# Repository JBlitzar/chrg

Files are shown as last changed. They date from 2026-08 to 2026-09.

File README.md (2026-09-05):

# chrg

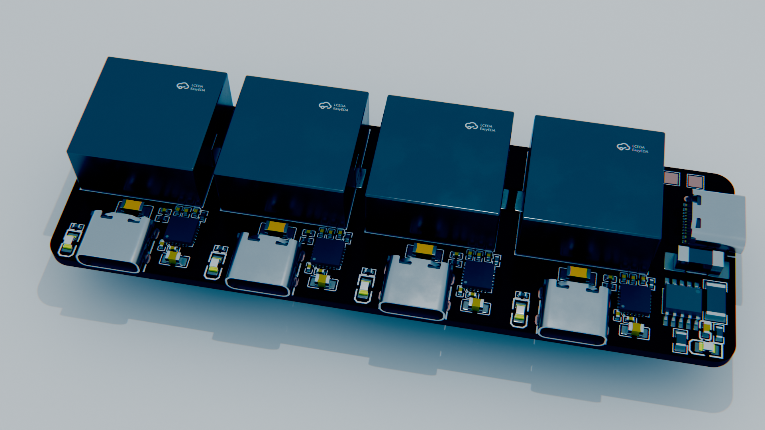
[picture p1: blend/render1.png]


chrg is a usbc charging hub. You can use it to charge your devices! It uses a CH224K PD sink as input, and then 4xIP6518 PD source controllers as output. 

Thanks to the IP6518, it should support:

 - 45W
 - USB-C Power Delivery
 - BC1.2 charging
 - Qualcomm QC2.0 and 3.0 charging
 - Apple, Huawei, Samsung, and Spreadtrum fast charging protocols
   - I don't have any huawei phones, but maybe you do! You can use chrg to charge them.

 Of course, YMMV when plugging in multiple devices. It's mostly bottlenecked by the wattage of your upstream brick (or alternatively 45W as the ip6518 spec says).

 ### Why I made this project

 I made this project because I like doing USB projects, and after making a [USB *data* hub](https://github.com/jblitzar/uhub), I thought it would be cool to make a *charging* hub. Plus, this way I can plug in one brick and charge my phone and headphones at the same time. I also think it's cool and was a way to learn a new chip (IP6518).

## Schematic

Root schematic:

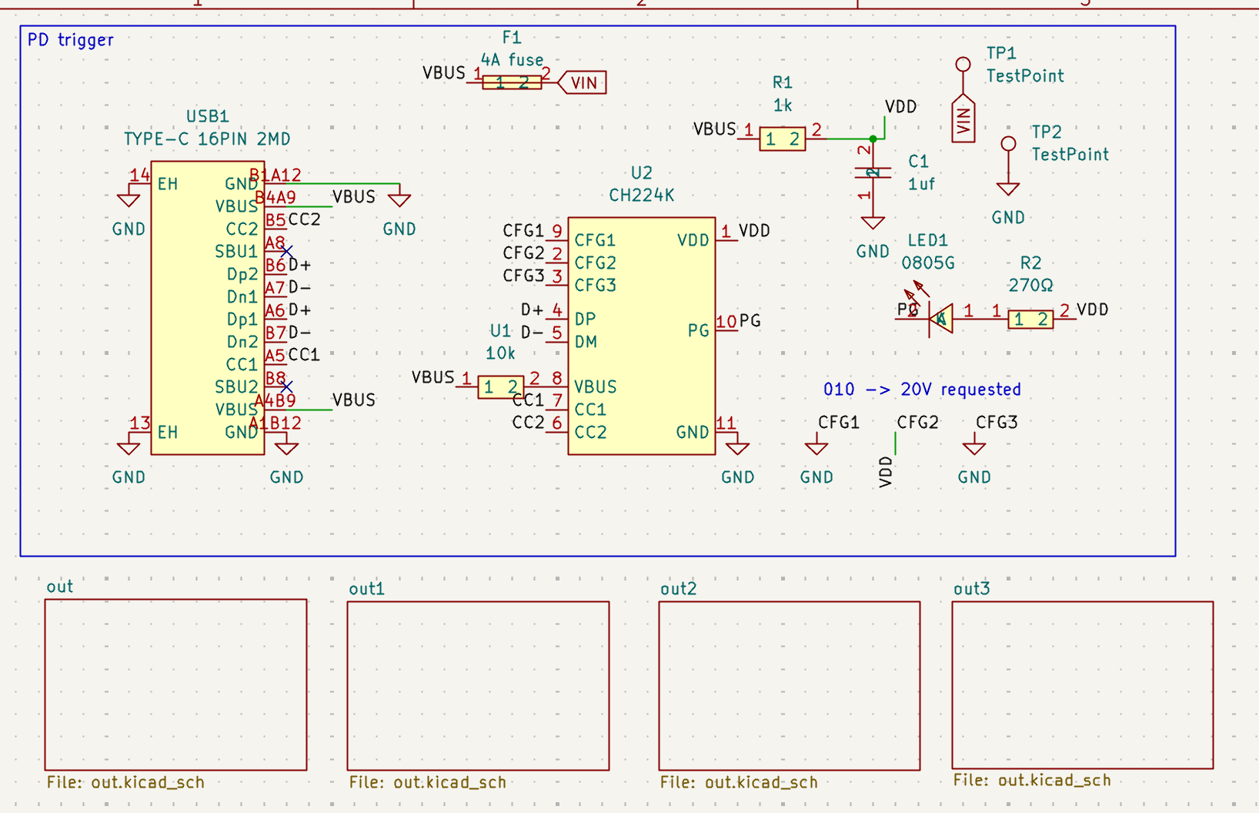
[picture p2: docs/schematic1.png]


Schematic for the `out` block:

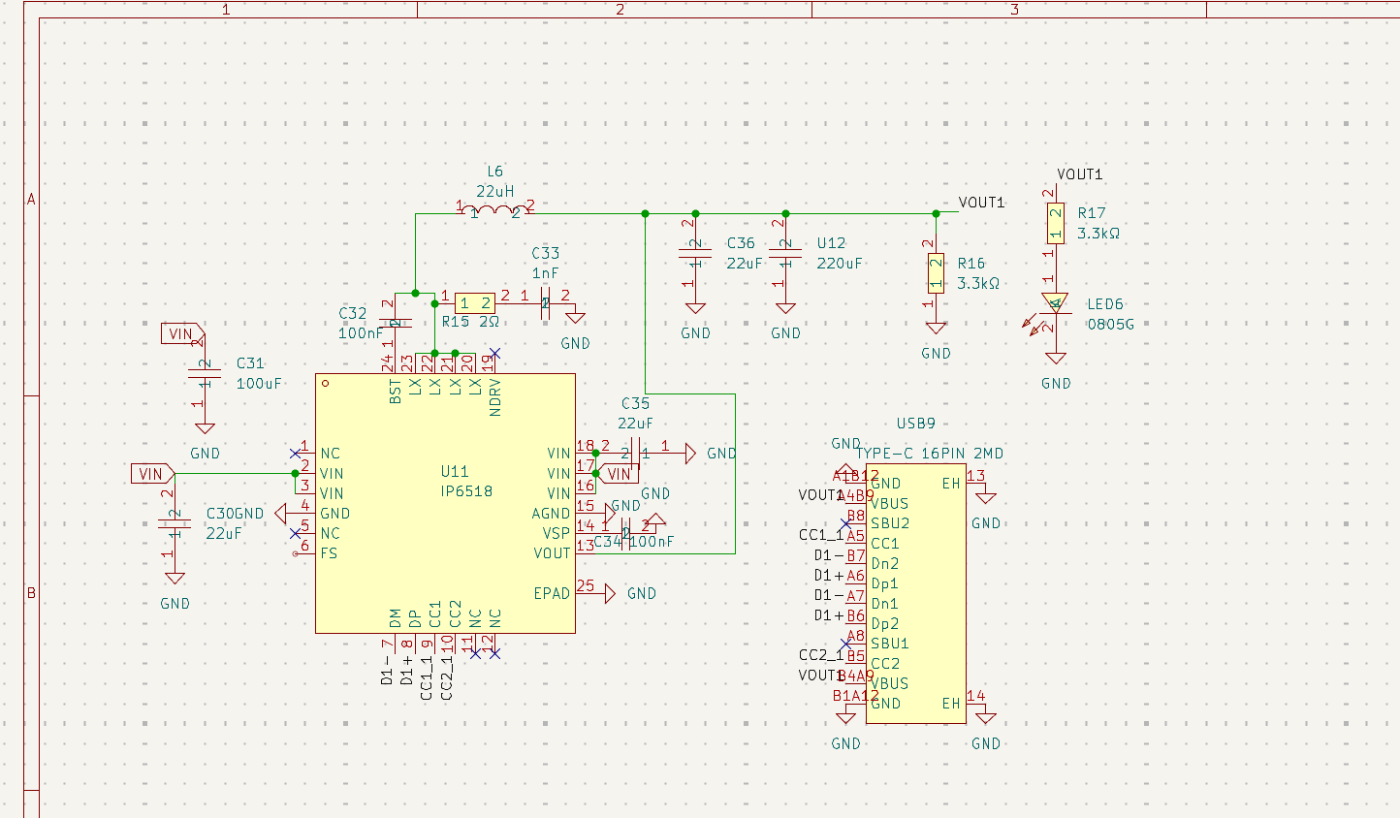
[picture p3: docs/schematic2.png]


## PCB

[View on Kicanvas](https://kicanvas.org/?repo=https%3A%2F%2Fgithub.com%2FJBlitzar%2Fchrg%2Ftree%2Fmain%2FPCB%2Fchrg)

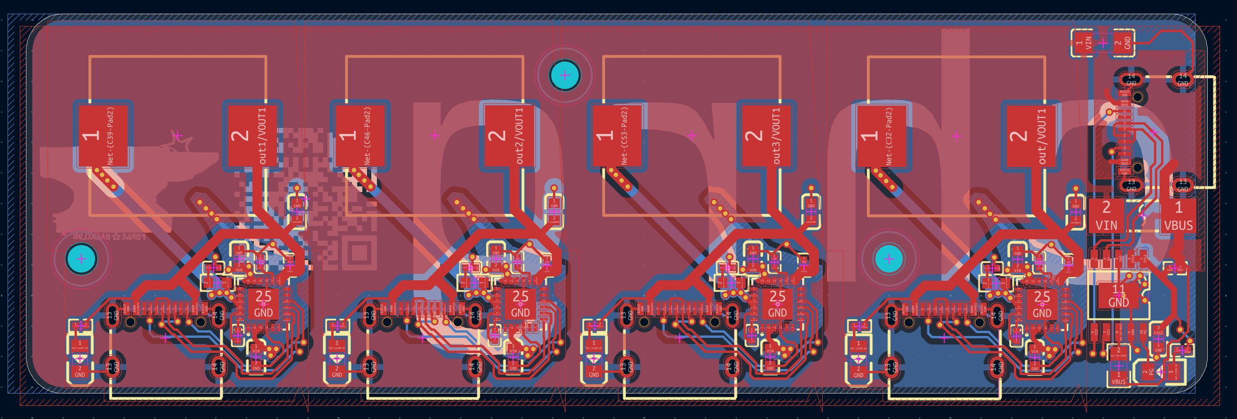
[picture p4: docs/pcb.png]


## CAD

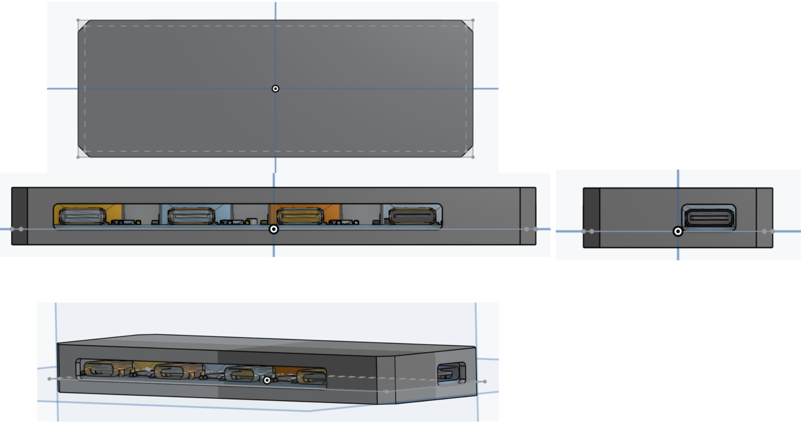
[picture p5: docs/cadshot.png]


[Onshape link](https://cad.onshape.com/documents/9567810a3a804626e0b9bd5e/w/546991992eff6807c34164d7/e/56ab2d679f572004bdd7b5fb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)

Assembly: [CAD/chrg_assembly.step](CAD/chrg_assembly.step)

Or just check the [CAD folder](CAD/)

PCB is held in place with the mounting holes

## How to use

### Assembly

Print chrg_case.step instead and slide it in from the side, like so:

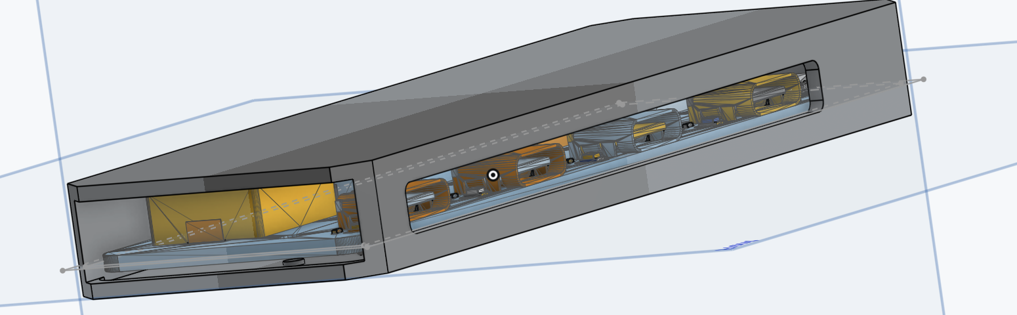
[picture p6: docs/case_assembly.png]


Then the pins should keep it secure. 

### Usage

Plug a usbc laptop charger into the side port. Then, charge your devices from the front ports!

## Testimonials

Don't just take it from me! Hear what users are saying about chrg

> *What are you making...*

> *this shit is not passing tsa bro*

> *Scary*

> *CHAAARGGGGEEEEEEE!!!!!!!!!!!!!!*

## BOM

|Item |link |Cost|Notes |
|---|---|----|---|
|5x PCB (moq) |N/A |4 |JLC |
|2x PCBA (moq) |N/A |45.87|JLC |
|JLC shipping + taxes |N/A |8 | |
|1x case |N/A |0 |I can print this myself|
|Total |N/A |57.87| |

### Fabrication BOM

Other fabrication outputs at [PCB/chrg/production](PCB/chrg/production)

|Designator |Footprint |Quantity|Value |LCSC Part #|Link|
|---|---|---|---|---|----|
|C1 |C0603 |1 |1uf |C15849 |[link](https://www.lcsc.com/product-detail/C15849.html)|
|C10, C11, C12, C13, C2, C3, C4, C5, C6, C7, C8, C9|C0603 |12 |22uF |C59461 |[link](https://www.lcsc.com/product-detail/C59461.html)|
|C14 |C1206 |1 |100uF |C15008 |[link](https://www.lcsc.com/product-detail/C15008.html)|
|C32, C34, C39, C41, C46, C48, C53, C55 |C0402 |8 |100nF |C1525 |[link](https://www.lcsc.com/product-detail/C1525.html)|
|C33, C40, C47, C54 |C0402 |4 |1nF |C1523 |[link](https://www.lcsc.com/product-detail/C1523.html)|
|F1 |FUSE-SMD_2410-T4A-125V |1 |4A fuse |C5220739 |[link](https://www.lcsc.com/product-detail/C5220739.html)|
|L1, L2, L3, L4 |IND-SMD_L14.4-W12.8 |4 |SLO1350H220MTT  |C364085 |[link](https://www.lcsc.com/product-detail/C364085.html)|
|LED1, LED6, LED7, LED8, LED9 |LED0805-R-RD |5 |0805G |C2297 |[link](https://www.lcsc.com/product-detail/C2297.html)|
|R16, R17, R19, R20, R21, R22, R23, R25, R26 |R0402 |9 |3.3kΩ |C25890 |[link](https://www.lcsc.com/product-detail/C25890.html)|
|R2 |R0402 |1 |1k |C11702 |[link](https://www.lcsc.com/product-detail/C11702.html)|
|R3, R4, R5, R6 |R0603 |4 |2Ω |C22977 |[link](https://www.lcsc.com/product-detail/C22977.html)|
|U1 |R0805 |1 |10k |C17414 |[link](https://www.lcsc.com/product-detail/C17414.html)|
|U11, U13, U15, U17 |QFN-24_L4.0-W4.0-P0.50-BL-EP2.6 |4 |IP6518 |C181688 |[link](https://www.lcsc.com/product-detail/C181688.html)|
|U2 |ESSOP-10_L4.9-W3.9-P1.0-LS6.0-TL-EP|1 |CH224K |C970725 |[link](https://www.lcsc.com/product-detail/C970725.html)|
|USB1, USB10, USB11, USB12, USB9 |USB-C-SMD_TYPE-C-16PIN-2MD-073 |5 |TYPE-C 16PIN 2MD|C2765186 |[link](https://www.lcsc.com/product-detail/C2765186.html)|

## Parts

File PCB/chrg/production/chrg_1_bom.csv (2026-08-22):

Designator | Footprint | Quantity | Value | LCSC Part #
C1 | C0603 | 1 | 1uf | C15849
C10, C11, C12, C13, C2, C3, C4, C5, C6, C7, C8, C9 | C0603 | 12 | 22uF | C59461
C14 | C1206 | 1 | 100uF | C15008
C32, C34, C39, C41, C46, C48, C53, C55 | C0402 | 8 | 100nF | C1525
C33, C40, C47, C54 | C0402 | 4 | 1nF | C1523
F1 | FUSE-SMD_2410-T4A-125V | 1 | 4A fuse | C5220739
L1, L2, L3, L4 | IND-SMD_L14.4-W12.8 | 4 | SLO1350H220MTT | C364085
LED1, LED6, LED7, LED8, LED9 | LED0805-R-RD | 5 | 0805G | C2297
R16, R17, R19, R20, R21, R22, R23, R25, R26 | R0402 | 9 | 3.3kΩ | C25890
R2 | R0402 | 1 | 1k | C11702
R3, R4, R5, R6 | R0603 | 4 | 2Ω | C22977
U1 | R0805 | 1 | 10k | C17414
U11, U13, U15, U17 | QFN-24_L4.0-W4.0-P0.50-BL-EP2.6 | 4 | IP6518 | C181688
U2 | ESSOP-10_L4.9-W3.9-P1.0-LS6.0-TL-EP | 1 | CH224K | C970725
USB1, USB10, USB11, USB12, USB9 | USB-C-SMD_TYPE-C-16PIN-2MD-073 | 5 | TYPE-C 16PIN 2MD | C2765186

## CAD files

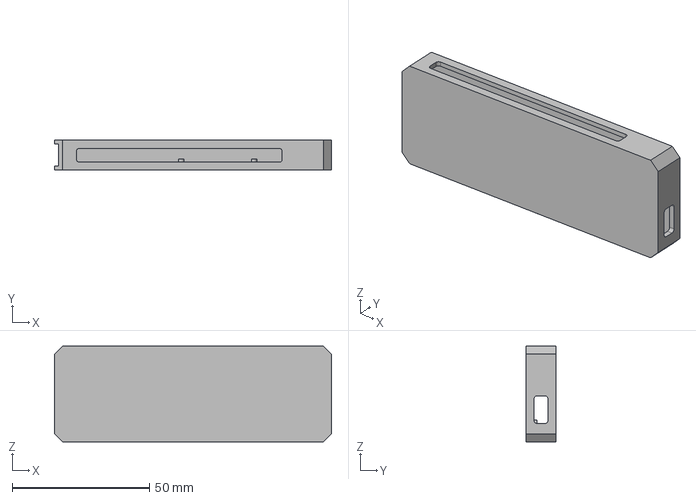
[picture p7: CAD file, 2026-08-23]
CAD/chrg_case.step
101.0 x 11.0 x 35.0 mm

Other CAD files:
blend/chrg.blend

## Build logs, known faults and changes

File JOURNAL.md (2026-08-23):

# Aug 17: Getting started

Got a rec from a peer to use IP6518. Architecture is:

- PD trigger in, else supply some lines
- IP6518 out per port

How many ports do I want? Probably more than two, but more than six seems excessive. Four is probably a good target for now.

Might buy a dedicated brick later, but charging off of laptop is fine for now, I guess.

Should I auto boost to some standard 20v or 24v in case PEBKAC plugs in a charger with weak PD that can't supply 20v? Probably not. I know my bricks. If no PG, it simply won't work.

Found a datasheet at https://www.tinytronics.nl/product_files/004122_IP6518-datasheet.pdf , schematic on page 8.

Yeah, made the rest of the design, copied it four times and changed the labels. Inductor sourcing was exciting but not too tricky. Ended up just putting one fuse. And I think LEDs for each is good UX. 

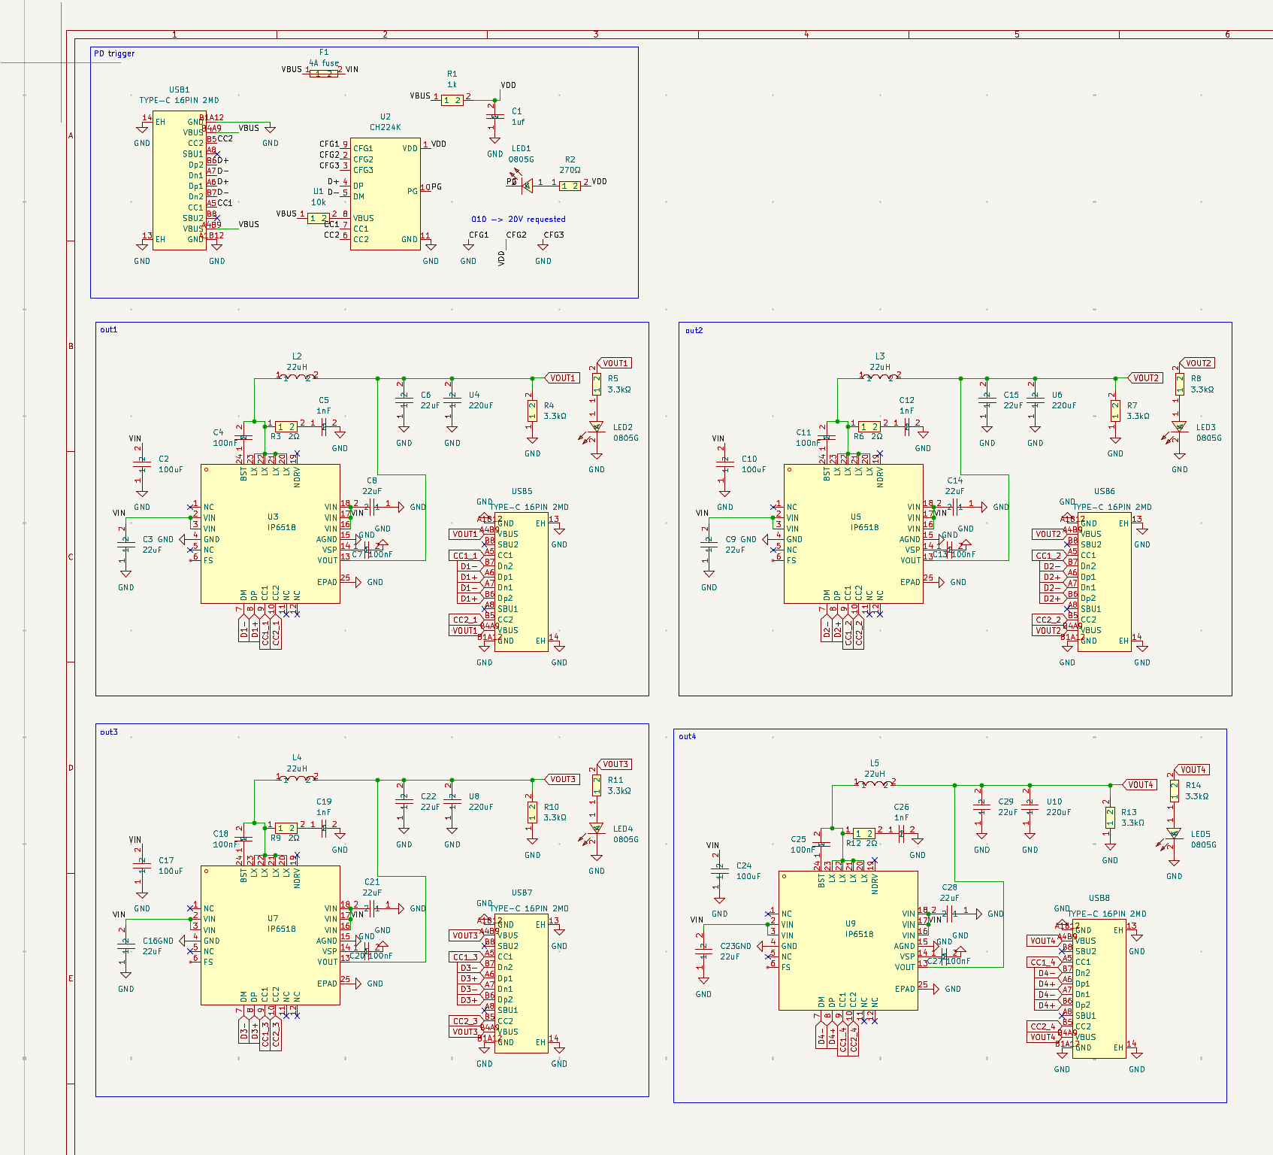
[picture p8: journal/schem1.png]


Time spent: 0.93 hours

# Aug 17: first pass on routing

QoL on the schematic, made it subsheets.

Got started on the layout!

I learned the "Multichannel" tooling in Kicad, which simplified things. This way I only have to place and route once!!

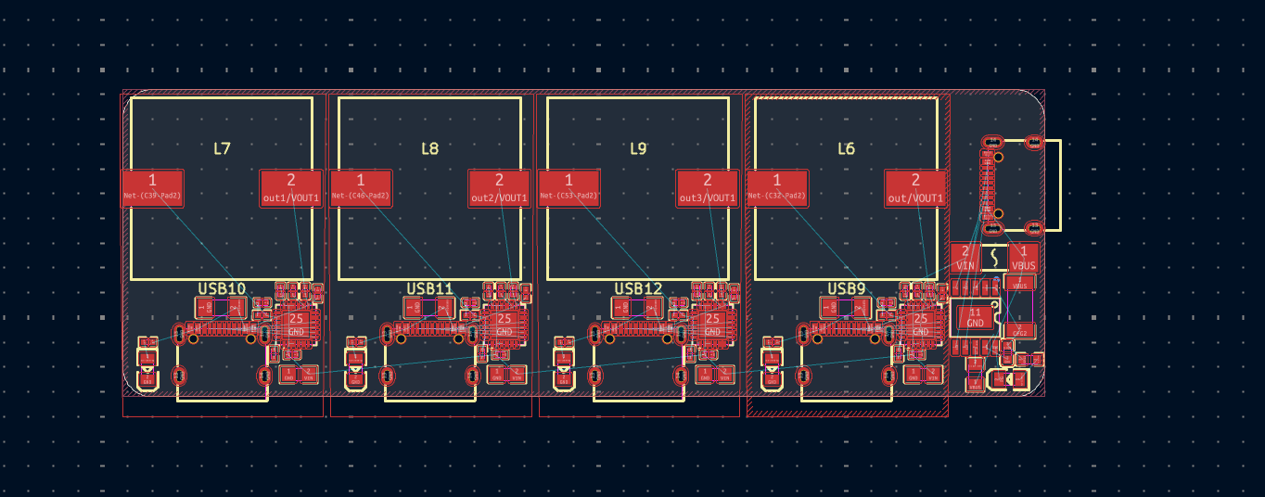
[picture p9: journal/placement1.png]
Finished placement 

aand finished routing. Man, it's so satisfying to click "repeat layout"

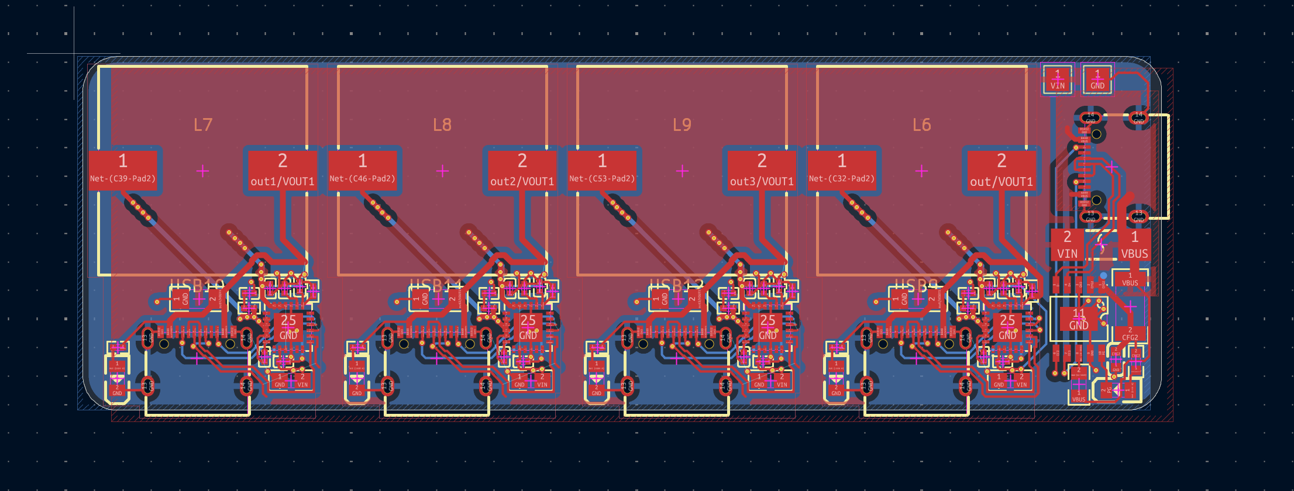
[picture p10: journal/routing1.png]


DRC was pretty minor, actually. Just one or two poorly placed vias, then bumped the clearance down to 0.15mm because jlc goes down to 0.09 or whatever. Ignore the annular width, that's irrelevant (easyeda2kicad footprints, I know)

But uh yeah!

Time tracking:

started 5:04 pm

ended 5:34

resumed 6:08

Ended 7:18

Time spent: 1.66 hours

# Aug 17: sk polish and render

Time tracking:
- Started 7:18
- Ended 7:54

Added a b.silkscreen, played around a little bit, and made a blender render!

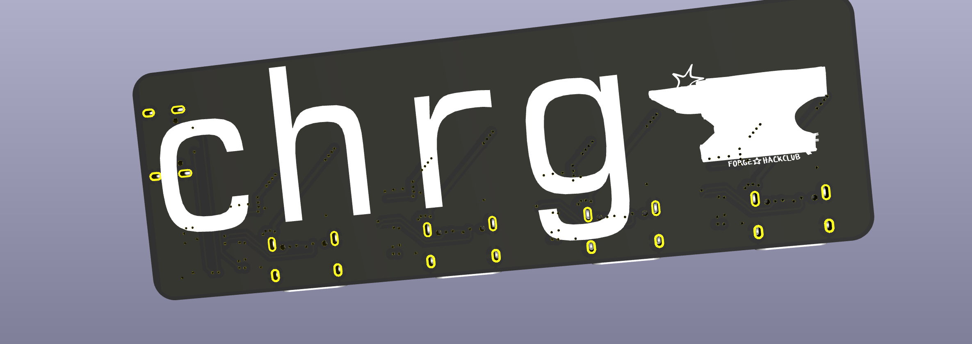
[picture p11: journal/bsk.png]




I think the blue color grading is cool. 

Honestly atp most design work was fun. Kind of a speedrun lol. I guess I'll write docs and stuff and see how my design review goes. 

Time spent: 0.61 hours

# Aug 18: README skeleton

Started in on the README. Fun to write. Probably my next step is to actually get a quote off of JLC and then polish off any and all requirements

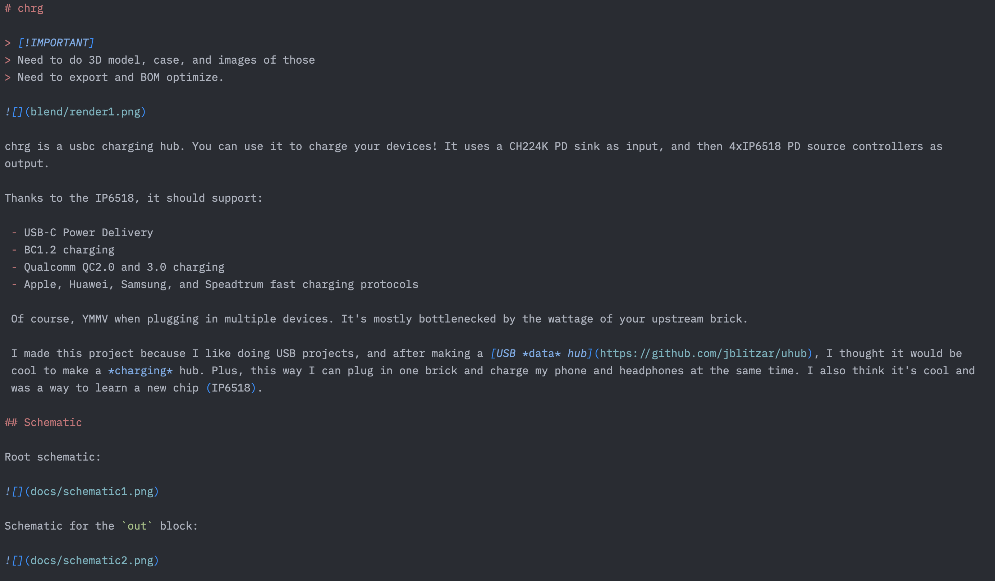
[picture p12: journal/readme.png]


Time spent: 0.3 hours

# Aug 18 BOM opt

Starting price for PCBA was $100 (zamn)

Started with the low-hanging-fruit Basic substitutions.

  - C1592 -> C15849
  - C131394 -> C1525
  - C14442 -> C1523
  - C137992 -> C25890
  - C2907219 -> C17414

Just those subs will bring PCBA cost down to 83.

And other substitutions that change footprint that I'll still make:

 - Use C59461 for the 22uF
 - use C15008 for the 100uF
 - use C22977 for the 2ohm

 Got sort of midway through the refactor.

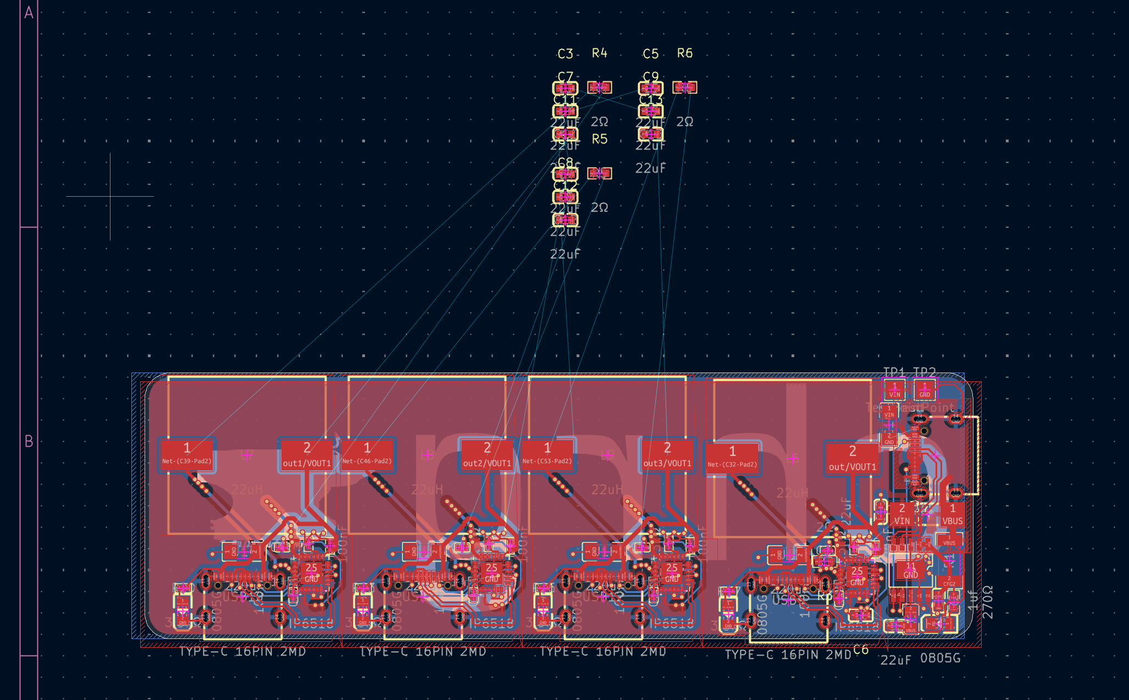
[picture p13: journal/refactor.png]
 

Time tracking:
 - started 8pm
 - Ended 8:52

Gonna deflate a little bit.

Time spent: 0.5 hours

# August 19 refactor

Placed the rest of the big caps, small session today. I might do a bit more later I guess. Only minor battles with DRC. tbd if the easyeda2kicad footprints are sus. Also deleted the test points because I can always desolder the global 100uf and use those as bodge pads. 

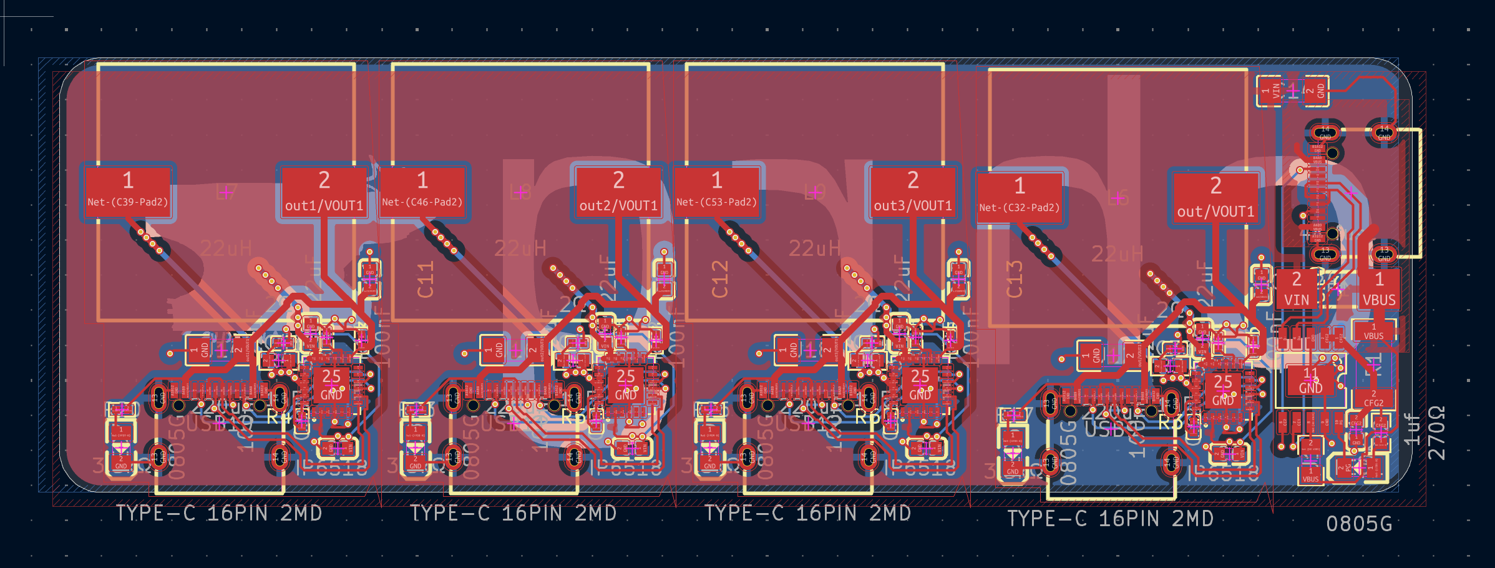
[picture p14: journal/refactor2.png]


Time spent: 0.25 hours

# August 20: Made it manufacturable and only committed one aesthetic atrocity

Because easyeda2kicad footprints suck, I have to make sure clearances acc work. Moved around some caps, clicked repeat layout. 

Only ONE weirdly tilted component lol

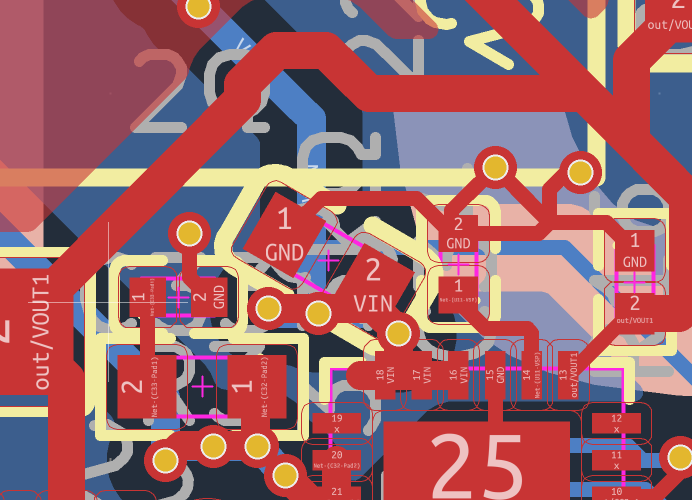
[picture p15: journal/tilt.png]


Time spent: 0.25 hours

# August 20: Aggressive BOM opt

Time for some intelligent component swapping.

Nuked the 220uFs. Now just one global 100uF.

There is only one LED resistor value, 3.3k.

Now PCBA cost is down to $57 !

genuinely BOM is starting to be irreducable. Actually cheap components matter.

Eating BOM:
 - inductors (see if can source better?? TBD)
 - IP6518 (the cheapest there is on LCSC, 8pcs genuinely is $12)
 - 1k ch224k resistor is extended, can probably source better

 Dicey stuff:
  - see if need fuse?
  - see if need CR decoupling on the 22uh vout line?

Found C364085 as a different inductor, should shave another $8.

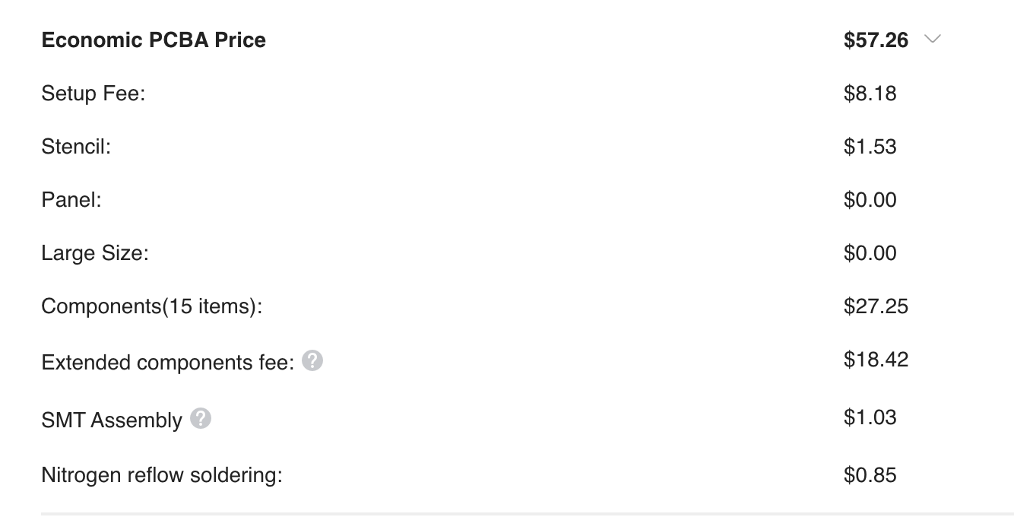
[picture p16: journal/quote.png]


Time spent: 1 hour

# August 21: Swapped the inductor, cleaned routing

Yeah! Made some thicker traces. this inductor is cheaper and smaller. It does have 3x the DCR, but that's okay I guess. It does change the look a bit too though.

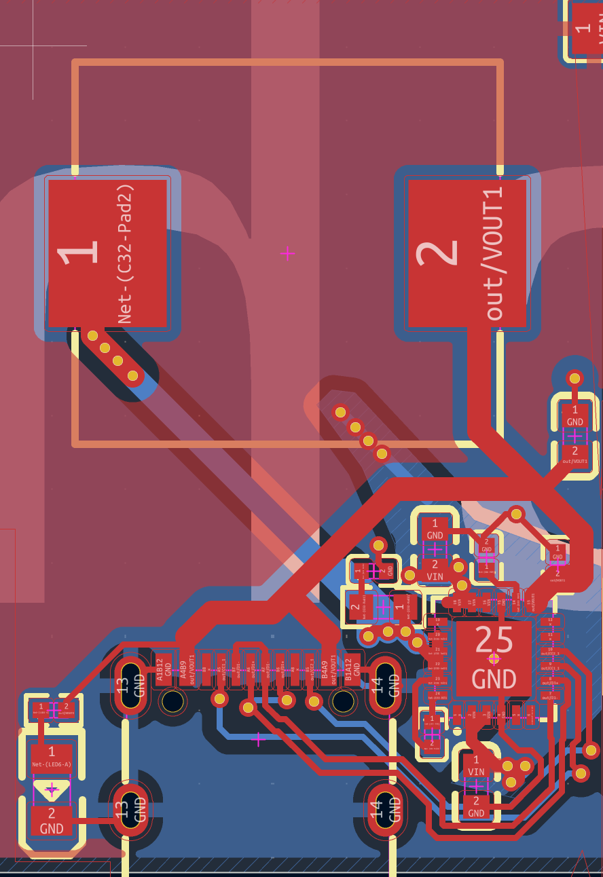
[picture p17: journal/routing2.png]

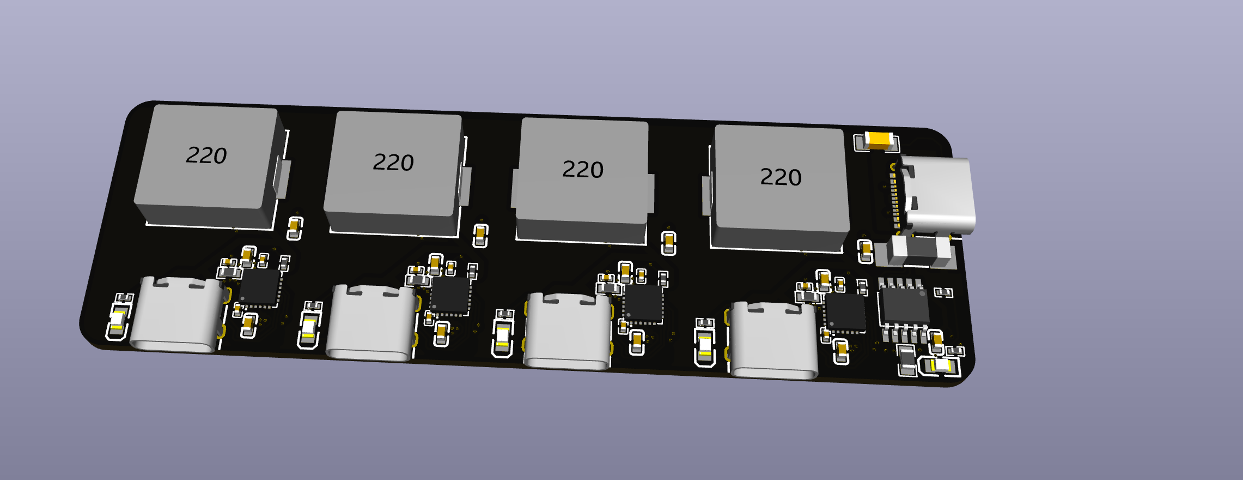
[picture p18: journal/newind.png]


Then I re-exported for the blender render. Spent a bit trying to get the colors right.

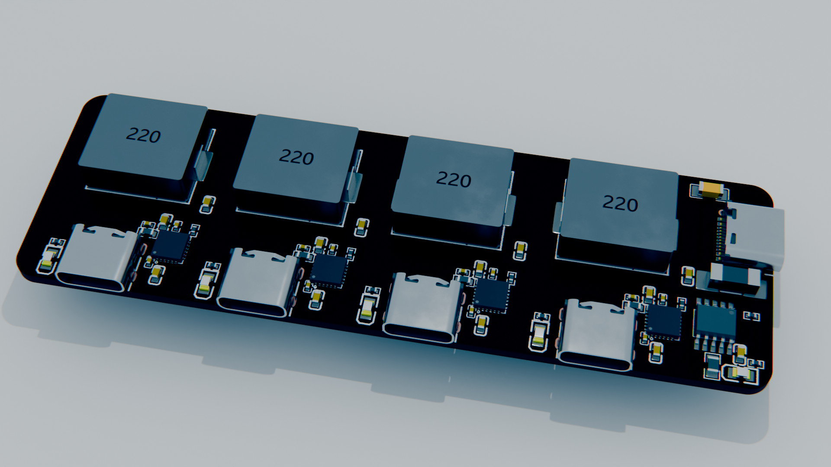
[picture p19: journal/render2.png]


Then I got another quote. Guess how much PCBA costs now??

That's right, $45 !!!

That is very much down from $100.

Since this is p much finalized / irreducable, I made the BOMs.

Time tracking
 - Started 4:20
 - ended 5:10
 - resumed 5:52
 - ended 6:02

Time spent: 1 hour

# August 21: messed around

I guess I will do a case after all.

Messed around with silkscreen, ended up just keeping the anvil and qr code in the end

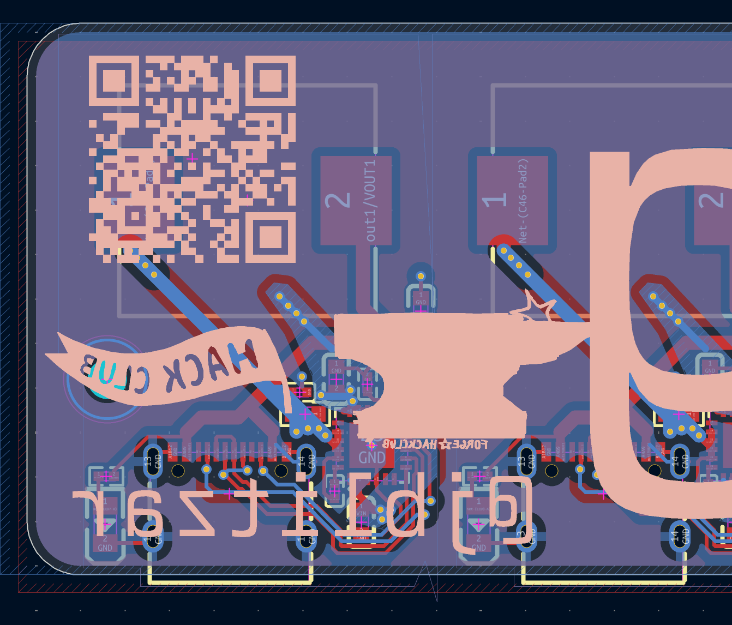
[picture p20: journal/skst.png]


And then I added mounting holes!! They are M2 because M3 was inconvenient to place. I can get m2 screws or use m2 3d printed fingers.

The triangle placement is pretty aura if i do say so myself

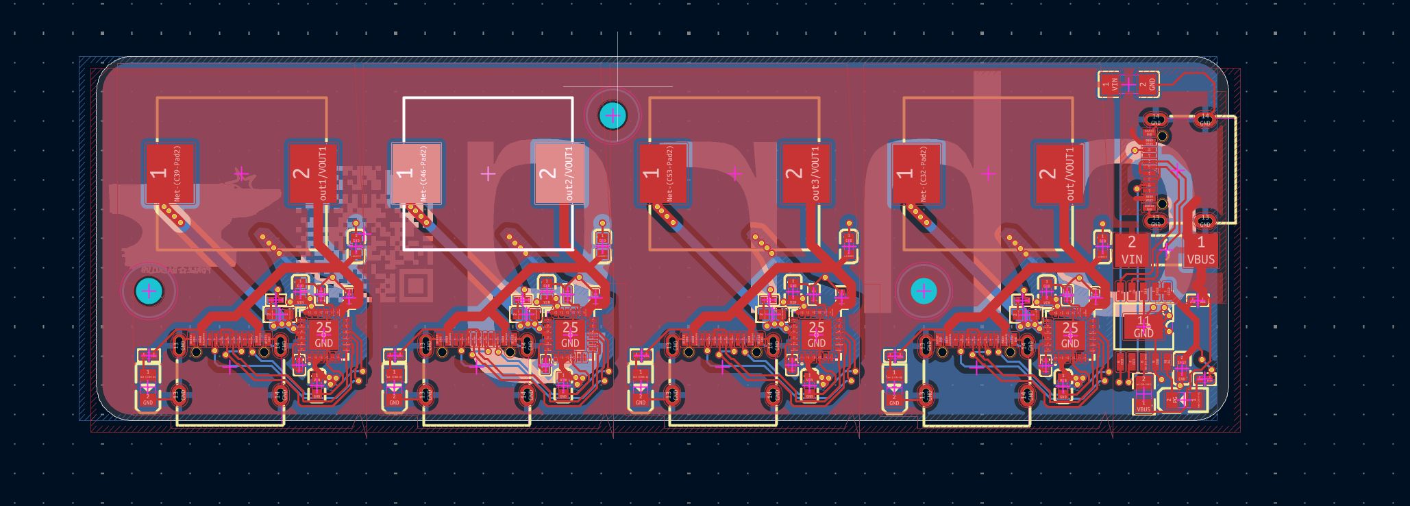
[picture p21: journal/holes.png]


Time spent: 0.3 hours

# August 22: Case

I made a case in Onshape. Chamferred the edges, added the holes. Internal fillet for structural integrity. Not much more to say I guess, this is how making enclosures goes?



Time spent: 1 hour

# August 23: Submission requirements

Went through the submission requirements, updated the README. Then I went through the elite review checklist requirements.

Added a hole in my case to make it actually assembleable 💀 



Time spent: 0.5 hours

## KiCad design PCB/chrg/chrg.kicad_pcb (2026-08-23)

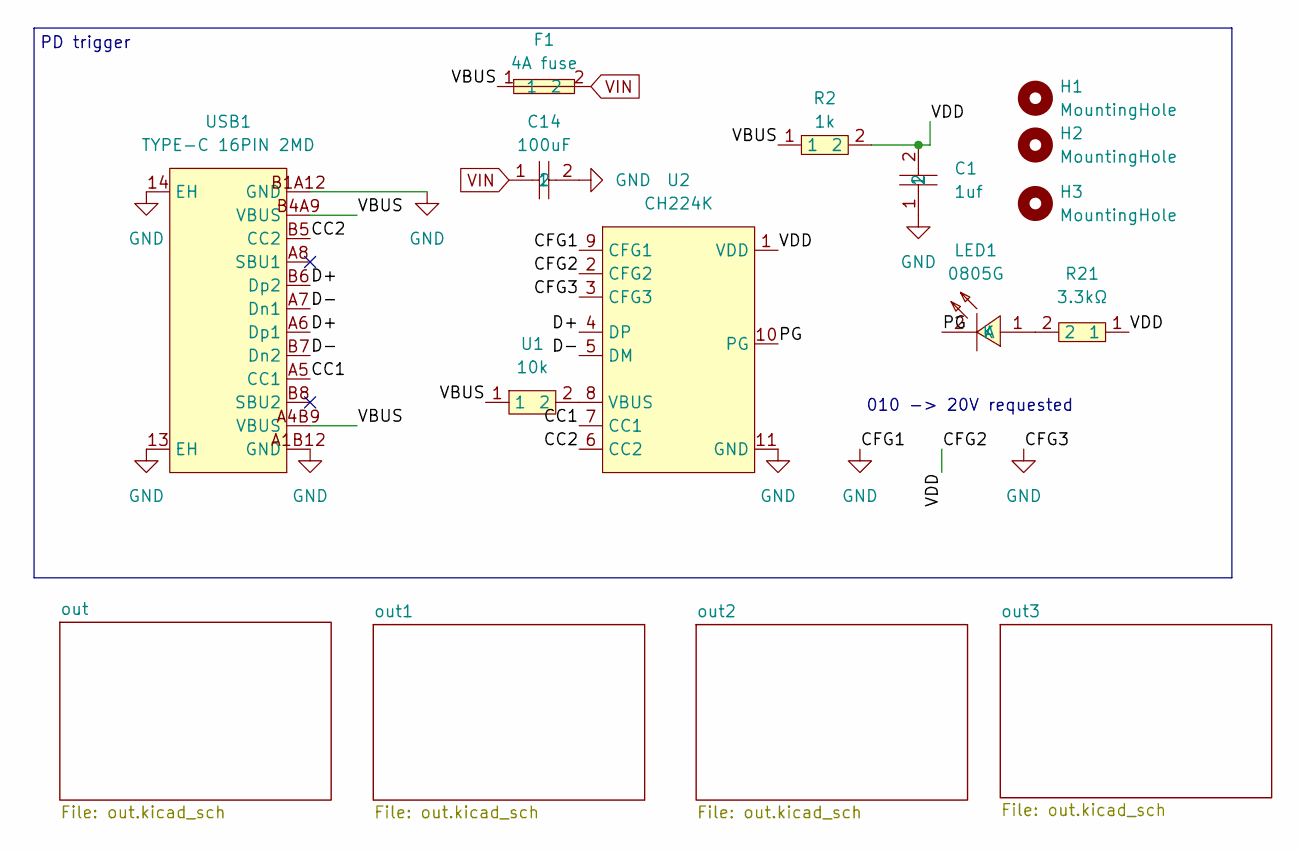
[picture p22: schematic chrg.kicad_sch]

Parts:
C1: 1uf; C0603; MPN CL10A105KB8NNNC; LCSC Part C15849
C14: 100uF; C1206; MPN CL31A107MQHNNNE; LCSC Part C15008
F1: 4A fuse; FUSE-SMD_2410-T4A-125V; MPN 2410 T4A/125V; LCSC Part C5220739
H1, H2, H3: MountingHole; MountingHole_2.2mm_M2
LED1: 0805G; LED0805-R-RD; MPN KT-0805G; LCSC Part C2297
R2: 1k; R0402; MPN 0402WGF1001TCE; LCSC Part C11702
R21: 3.3kΩ; R0402; MPN 0402WGF3301TCE; LCSC Part C25890
U1: 10k; R0805; MPN 0805W8F1002T5E; LCSC Part C17414
U2: CH224K; ESSOP-10_L4.9-W3.9-P1.0-LS6.0-TL-EP; MPN CH224K; LCSC Part C970725
USB1: TYPE-C 16PIN 2MD; USB-C-SMD_TYPE-C-16PIN-2MD-073; MPN TYPE-C 16PIN 2MD(073); LCSC Part C2765186

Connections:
/CC1: U2.7 (CC1), USB1.A5 (CC1)
/CC2: U2.6 (CC2), USB1.B5 (CC2)
/CFG2: C1.2, R2.2, R21.1, U2.1 (VDD), U2.2 (CFG2)
/D+: U2.4 (DP), USB1.A6 (Dp1), USB1.B6 (Dp2)
/D-: U2.5 (DM), USB1.A7 (Dn1), USB1.B7 (Dn2)
/PG: LED1.2 (K), U2.10 (PG)
/VBUS: F1.1, R2.1, U1.1, USB1.A4B9 (VBUS), USB1.B4A9 (VBUS)
GND: C1.1, C14.2, U2.3 (CFG3), U2.9 (CFG1), U2.11 (GND), USB1.13 (EH), USB1.14 (EH), USB1.A1B12 (GND), USB1.B1A12 (GND); also elsewhere on the board
unnamed: LED1.1 (A), R21.2
unnamed: U1.2, U2.8 (VBUS)
VIN: C14.1, F1.2; also elsewhere on the board

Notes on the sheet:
PD trigger
010 -> 20V requested

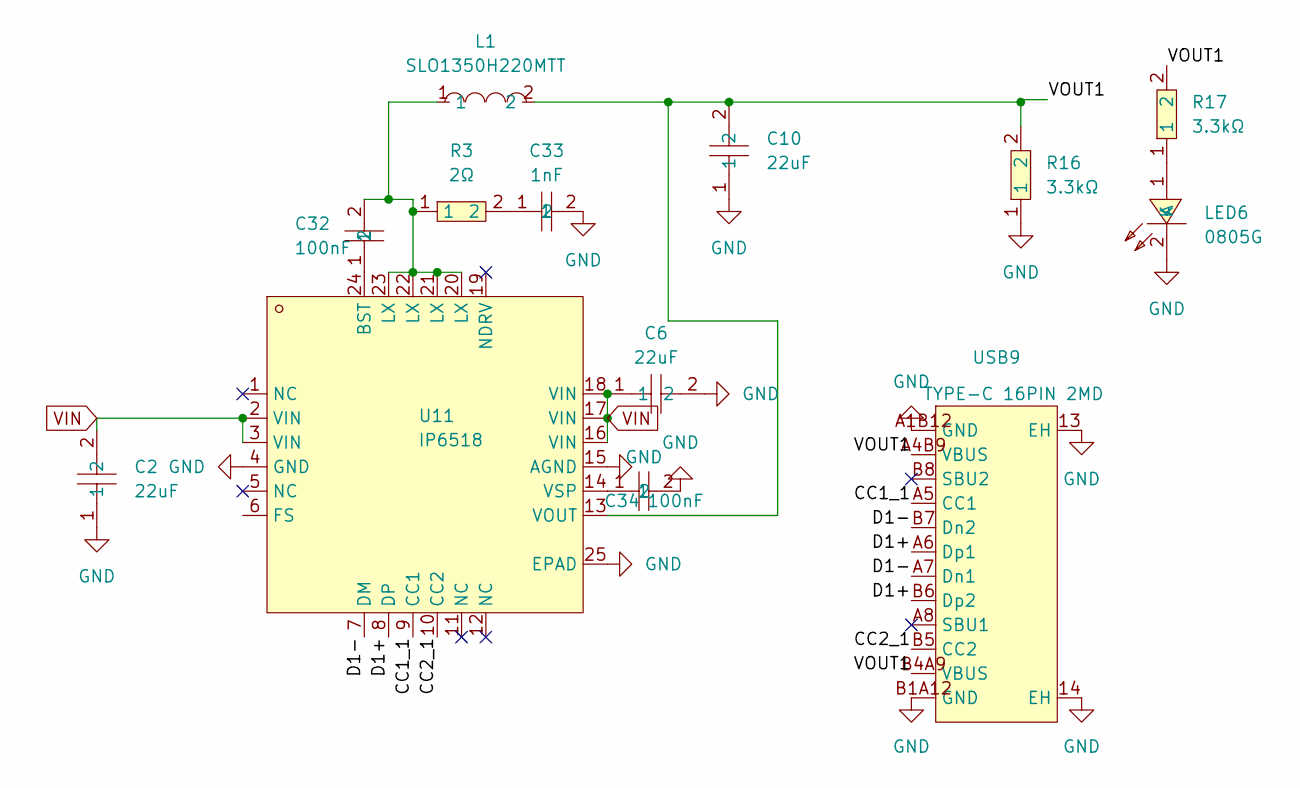
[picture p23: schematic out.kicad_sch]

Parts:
C2, C6, C10: 22uF; C0603; MPN CL10A226MQ8NRNC; LCSC Part C59461
C32, C34: 100nF; C0402; MPN CL05B104KO5NNNC; LCSC Part C1525
C33: 1nF; C0402; MPN 0402B102K500NT; LCSC Part C1523
L1: SLO1350H220MTT; IND-SMD_L14.4-W12.8; MPN SLO1350H220MTT; LCSC Part C364085
LED6: 0805G; LED0805-R-RD; MPN KT-0805G; LCSC Part C2297
R3: 2Ω; R0603; MPN 0603WAF200KT5E; LCSC Part C22977
R16, R17: 3.3kΩ; R0402; MPN 0402WGF3301TCE; LCSC Part C25890
U11: IP6518; QFN-24_L4.0-W4.0-P0.50-BL-EP2.6; MPN IP6518; LCSC Part C181688
USB9: TYPE-C 16PIN 2MD; USB-C-SMD_TYPE-C-16PIN-2MD-073; MPN TYPE-C 16PIN 2MD(073); LCSC Part C2765186

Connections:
/out/CC1_1: U11.9 (CC1), USB9.A5 (CC1)
/out/CC2_1: U11.10 (CC2), USB9.B5 (CC2)
/out/D1+: U11.8 (DP), USB9.A6 (Dp1), USB9.B6 (Dp2)
/out/D1-: U11.7 (DM), USB9.A7 (Dn1), USB9.B7 (Dn2)
/out/VOUT1: C10.2, L1.2, R16.2, R17.2, U11.13 (VOUT), USB9.A4B9 (VBUS), USB9.B4A9 (VBUS)
GND: C2.1, C6.2, C10.1, C33.2, C34.2, LED6.2 (K), R16.1, U11.4 (GND), U11.15 (AGND), U11.25 (EPAD), USB9.13 (EH), USB9.14 (EH), USB9.A1B12 (GND), USB9.B1A12 (GND); also elsewhere on the board
unnamed: C32.2, L1.1, R3.1, U11.20 (LX), U11.21 (LX), U11.22 (LX), U11.23 (LX)
unnamed: C33.1, R3.2
unnamed: LED6.1 (A), R17.1
unnamed: C32.1, U11.24 (BST)
unnamed: C34.1, U11.14 (VSP)
VIN: C2.2, C6.1, U11.2 (VIN), U11.3 (VIN), U11.16 (VIN), U11.17 (VIN), U11.18 (VIN); also elsewhere on the board

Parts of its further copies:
C3, C4, C5, C7, C8, C9, C11, C12, C13: 22uF; C0603; MPN CL10A226MQ8NRNC; LCSC Part C59461
C39, C41, C46, C48, C53, C55: 100nF; C0402; MPN CL05B104KO5NNNC; LCSC Part C1525
C40, C47, C54: 1nF; C0402; MPN 0402B102K500NT; LCSC Part C1523
L2, L3, L4: SLO1350H220MTT; IND-SMD_L14.4-W12.8; MPN SLO1350H220MTT; LCSC Part C364085
LED7, LED8, LED9: 0805G; LED0805-R-RD; MPN KT-0805G; LCSC Part C2297
R4, R5, R6: 2Ω; R0603; MPN 0603WAF200KT5E; LCSC Part C22977
R19, R20, R22, R23, R25, R26: 3.3kΩ; R0402; MPN 0402WGF3301TCE; LCSC Part C25890
U13, U15, U17: IP6518; QFN-24_L4.0-W4.0-P0.50-BL-EP2.6; MPN IP6518; LCSC Part C181688
USB10, USB11, USB12: TYPE-C 16PIN 2MD; USB-C-SMD_TYPE-C-16PIN-2MD-073; MPN TYPE-C 16PIN 2MD(073); LCSC Part C2765186

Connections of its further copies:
/out1/CC1_1: U13.9 (CC1), USB10.A5 (CC1)
/out1/CC2_1: U13.10 (CC2), USB10.B5 (CC2)
/out1/D1+: U13.8 (DP), USB10.A6 (Dp1), USB10.B6 (Dp2)
/out1/D1-: U13.7 (DM), USB10.A7 (Dn1), USB10.B7 (Dn2)
/out1/VOUT1: C11.2, L2.2, R19.2, R20.2, U13.13 (VOUT), USB10.A4B9 (VBUS), USB10.B4A9 (VBUS)
/out2/CC1_1: U15.9 (CC1), USB11.A5 (CC1)
/out2/CC2_1: U15.10 (CC2), USB11.B5 (CC2)
/out2/D1+: U15.8 (DP), USB11.A6 (Dp1), USB11.B6 (Dp2)
/out2/D1-: U15.7 (DM), USB11.A7 (Dn1), USB11.B7 (Dn2)
/out2/VOUT1: C12.2, L3.2, R22.2, R23.2, U15.13 (VOUT), USB11.A4B9 (VBUS), USB11.B4A9 (VBUS)
/out3/CC1_1: U17.9 (CC1), USB12.A5 (CC1)
/out3/CC2_1: U17.10 (CC2), USB12.B5 (CC2)
/out3/D1+: U17.8 (DP), USB12.A6 (Dp1), USB12.B6 (Dp2)
/out3/D1-: U17.7 (DM), USB12.A7 (Dn1), USB12.B7 (Dn2)
/out3/VOUT1: C13.2, L4.2, R25.2, R26.2, U17.13 (VOUT), USB12.A4B9 (VBUS), USB12.B4A9 (VBUS)
GND: C3.1, C4.1, C5.1, C7.2, C8.2, C9.2, C11.1, C12.1, C13.1, C40.2, C41.2, C47.2, C48.2, C54.2, C55.2, LED7.2 (K), LED8.2 (K), LED9.2 (K), R19.1, R22.1, R25.1, U13.4 (GND), U13.15 (AGND), U13.25 (EPAD), U15.4 (GND), U15.15 (AGND), U15.25 (EPAD), U17.4 (GND), U17.15 (AGND), U17.25 (EPAD), USB10.13 (EH), USB10.14 (EH), USB10.A1B12 (GND), USB10.B1A12 (GND), USB11.13 (EH), USB11.14 (EH), USB11.A1B12 (GND), USB11.B1A12 (GND), USB12.13 (EH), USB12.14 (EH), USB12.A1B12 (GND), USB12.B1A12 (GND); also elsewhere on the board
unnamed: C39.2, L2.1, R4.1, U13.20 (LX), U13.21 (LX), U13.22 (LX), U13.23 (LX)
unnamed: C40.1, R4.2
unnamed: C46.2, L3.1, R5.1, U15.20 (LX), U15.21 (LX), U15.22 (LX), U15.23 (LX)
unnamed: C47.1, R5.2
unnamed: C53.2, L4.1, R6.1, U17.20 (LX), U17.21 (LX), U17.22 (LX), U17.23 (LX)
unnamed: C54.1, R6.2
unnamed: LED7.1 (A), R20.1
unnamed: LED8.1 (A), R23.1
unnamed: LED9.1 (A), R26.1
unnamed: C39.1, U13.24 (BST)
unnamed: C41.1, U13.14 (VSP)
unnamed: C46.1, U15.24 (BST)
unnamed: C48.1, U15.14 (VSP)
unnamed: C53.1, U17.24 (BST)
unnamed: C55.1, U17.14 (VSP)
VIN: C3.2, C4.2, C5.2, C7.1, C8.1, C9.1, U13.2 (VIN), U13.3 (VIN), U13.16 (VIN), U13.17 (VIN), U13.18 (VIN), U15.2 (VIN), U15.3 (VIN), U15.16 (VIN), U15.17 (VIN), U15.18 (VIN), U17.2 (VIN), U17.3 (VIN), U17.16 (VIN), U17.17 (VIN), U17.18 (VIN); also elsewhere on the board

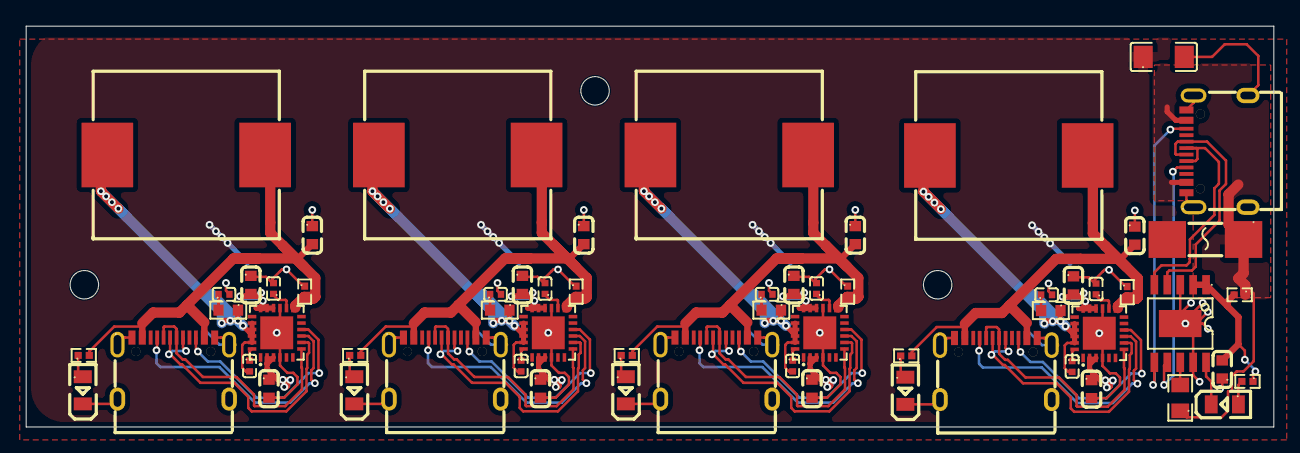
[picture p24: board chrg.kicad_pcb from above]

Board: 2 copper layers, 96.5 x 31.0 mm, 65 parts (1 on the bottom side), 51 nets.

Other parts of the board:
kobee-studio-6A88F8E8: Kobee Studio; kobee-studio-6A88F8A7

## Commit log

2026-08-18 schem "done"
    [chrg.kicad_sch]
2026-08-18 routed the board
    [chrg.kicad_pcb, chrg.kicad_sch, out.kicad_sch]
2026-08-18 should be correct now
    [chrg.kicad_pcb]
2026-08-18 start of a README
    [chrg_1_bom.csv, chrg_1_designators.csv, chrg_1_positions.csv]
2026-08-22 Revert "a"
    This reverts commit b5d0d695043d5ed199ddc9a2896fb7234a4ad550.
    [BOM.csv]
2026-08-23 how to use
    [chrg_case.step]
2026-08-23 re-export gerbers
    [chrg_1_designators.csv, chrg_1_positions.csv]
